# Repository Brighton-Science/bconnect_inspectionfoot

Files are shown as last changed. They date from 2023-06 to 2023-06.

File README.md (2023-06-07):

# The BC Mobile & Surface Analyst Custom Inspection Attachment

## INTRODUCTION:
This readme is intended to help the end user successfully design and fabricate their own custom foot known as a CIA(Custom Inspection Attachment).

## DESCRIPTION:
The standard attachment works very well mating to a flat surface. It does not facilitate the ability to measure on surfaces that have more complex features or geometry. 

3D printing technology allows a mechanical designer to create a CIA in house to quickly adapt the Surface Analyst to their particular substrate(s).  Although many additive manufactoring techiques are available the primary design intent for the information provided is for FDM printing using black material.

## USAGE:
Using both .pdf files of the “Tethered Universal head template” and “Tethered Universal CIA template” blueprints, design and fabrication of a CIA is made easier. Critical dimensions and noted drop placement will assist in helping construct a CIA that successfully allows the technician the ability to land a drop properly and gather contact angle readings. Both .pdf files will also provide the dimensional information required to use the 1/4-20 mounting features on the side of the measurement head.

Using the .stp files of both the “Tethered Universal head template” and “Tethered Universal CIA template” will allow the CAD designer to interface with the architecture directly.  Material can be added or removed to allow the designer to make proper engagement with the mating geometry.

## ASSISTANCE:
For more information or to request a quote for Brighton Science CIA services visit the site below:

https://www.brighton-science.com/solutions/non-networked-solutions/accessories-fixtures

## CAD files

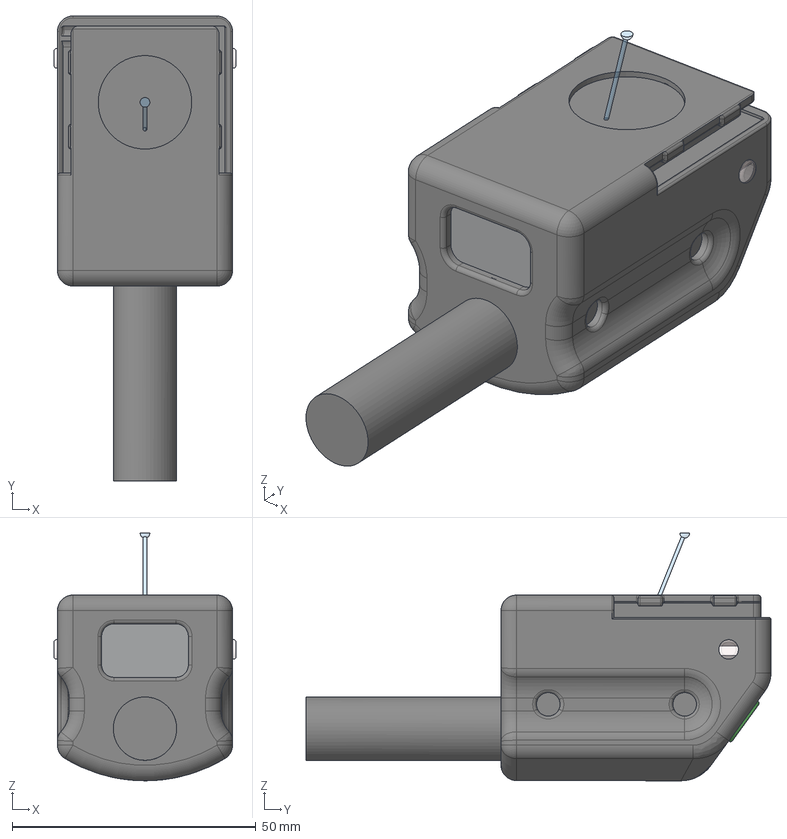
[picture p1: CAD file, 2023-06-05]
Tethered Universal Head template.stp
37.3 x 95.4 x 50.8 mm

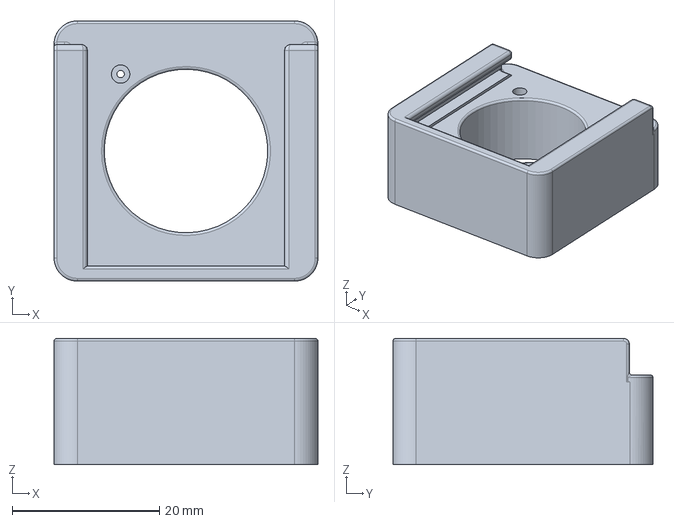
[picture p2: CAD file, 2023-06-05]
Tethered Universal CIA template.stp
35.9 x 35.4 x 17.2 mm

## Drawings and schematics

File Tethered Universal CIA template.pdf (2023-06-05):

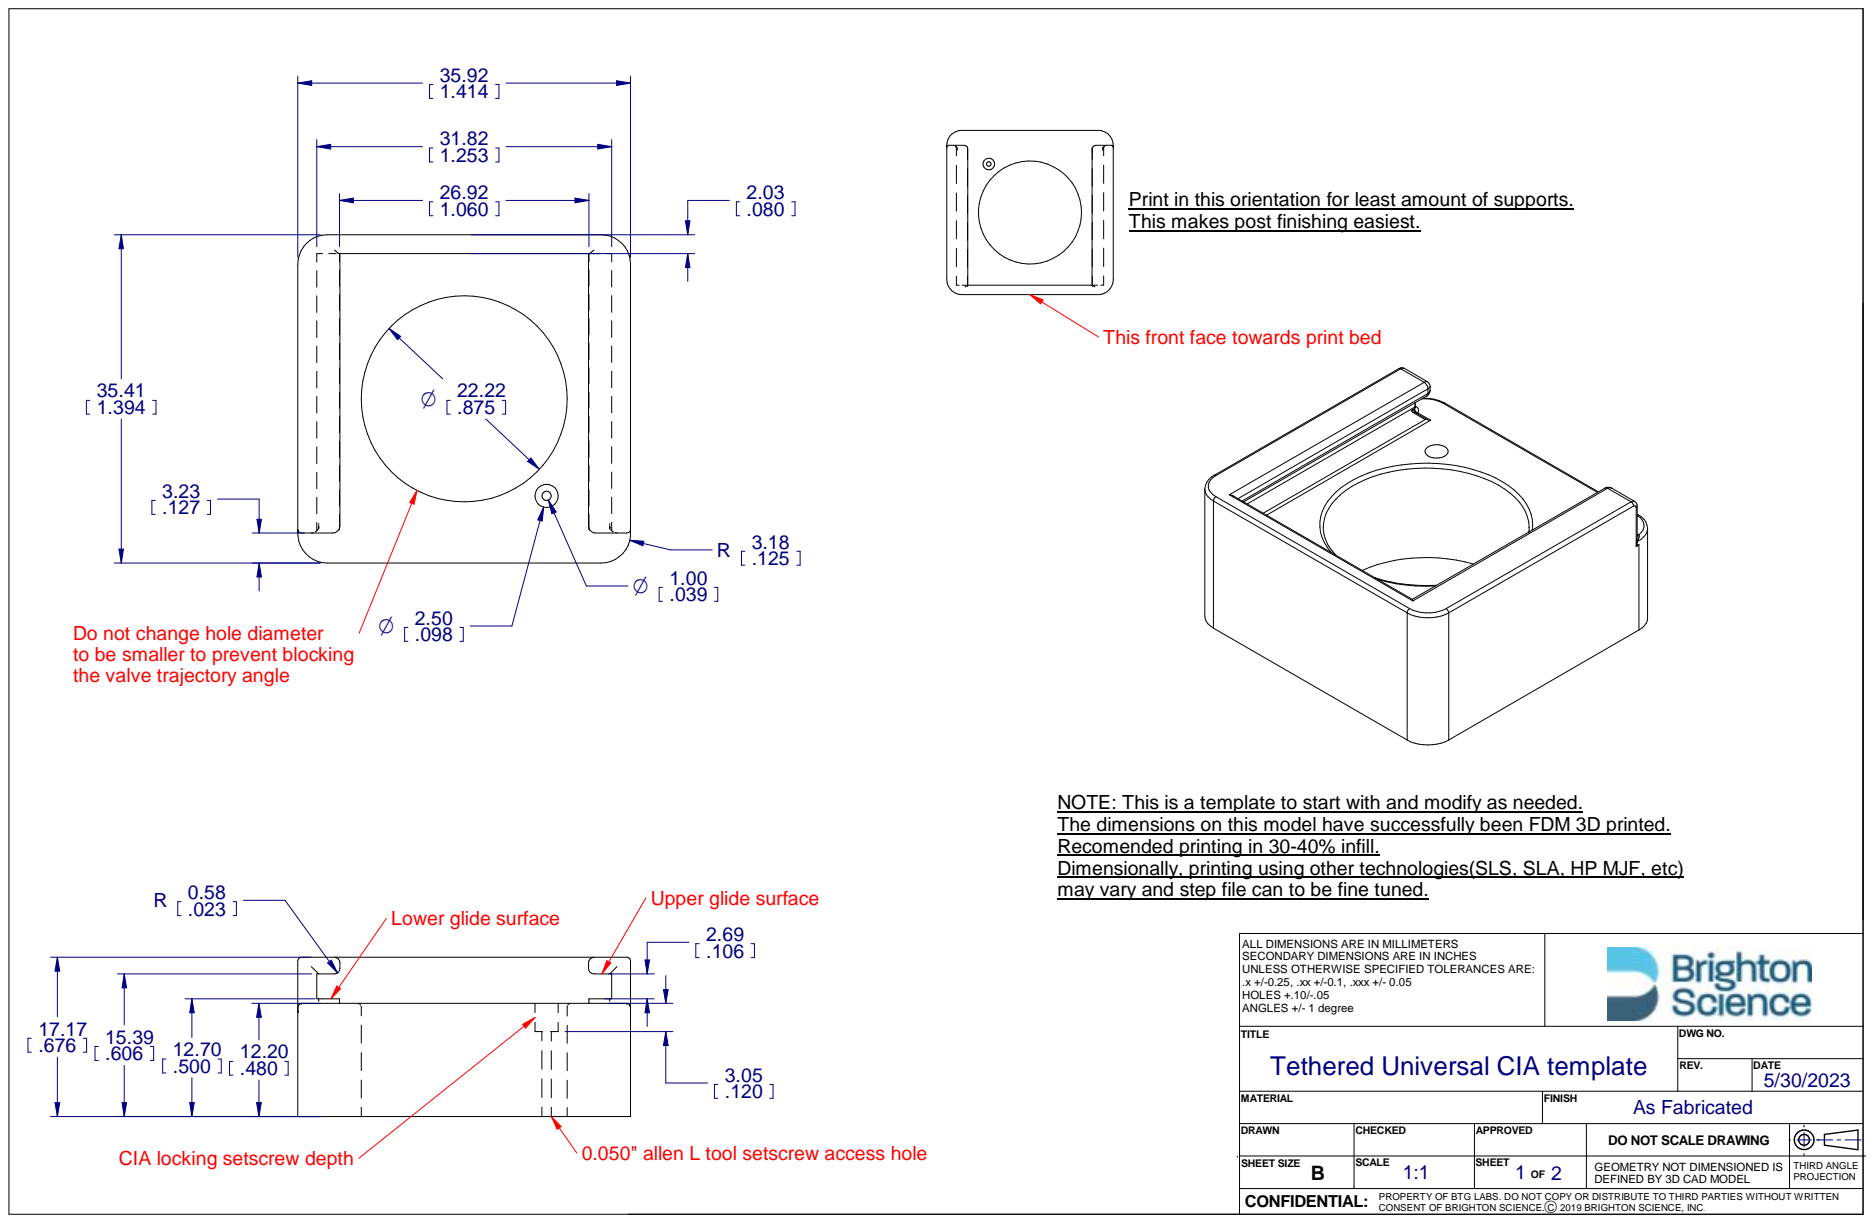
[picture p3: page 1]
CONFIDENTIAL:

Print in this orientation for least amount of supports.
This makes post finishing easiest.

This front face towards print bed

Do not change hole diameter
to be smaller to prevent blocking
the valve trajectory angle

NOTE: This is a template to start with and modify as needed.
The dimensions on this model have successfully been FDM 3D printed.
Recomended printing in 30-40% infill.
Dimensionally, printing using other technologies(SLS, SLA, HP MJF, etc)

may vary and step file can to be fine tuned. Upper glide surface

Lower glide surface

ALL DIMENSIONS ARE IN MILLIMETERS SECONDARY DIMENSIONS ARE IN INCHES UNLESS OTHERWISE SPECIFIED TOLERANCES ARE: .x +/-0.25, .xx +/-0.1, .xxx +/- 0.05 HOLES +.10/-.05 ANGLES +/- 1 degree

TITLE Tethered Universal CIA template | DWG NO.

REV. | DATE 5/30/2023

MATERIAL | FINISH As Fabricated

DRAWN | CHECKED | APPROVED | DO NOT SCALE DRAWING

0.050" allen L tool setscrew access hole

CIA locking setscrew depth

SHEET SIZE B | SCALE | SHEET 1 | GEOMETRY NOT DIMENSIONED IS DEFINED BY 3D CAD MODEL | THIRD ANGLE PROJECTION

PROPERTY OF BTG LABS. DO NOT COPY OR DISTRIBUTE TO THIRD PARTIES WITHOUT WRITTEN
CONSENT OF BRIGHTON SCIENCE. C 2019 BRIGHTON SCIENCE, INC.

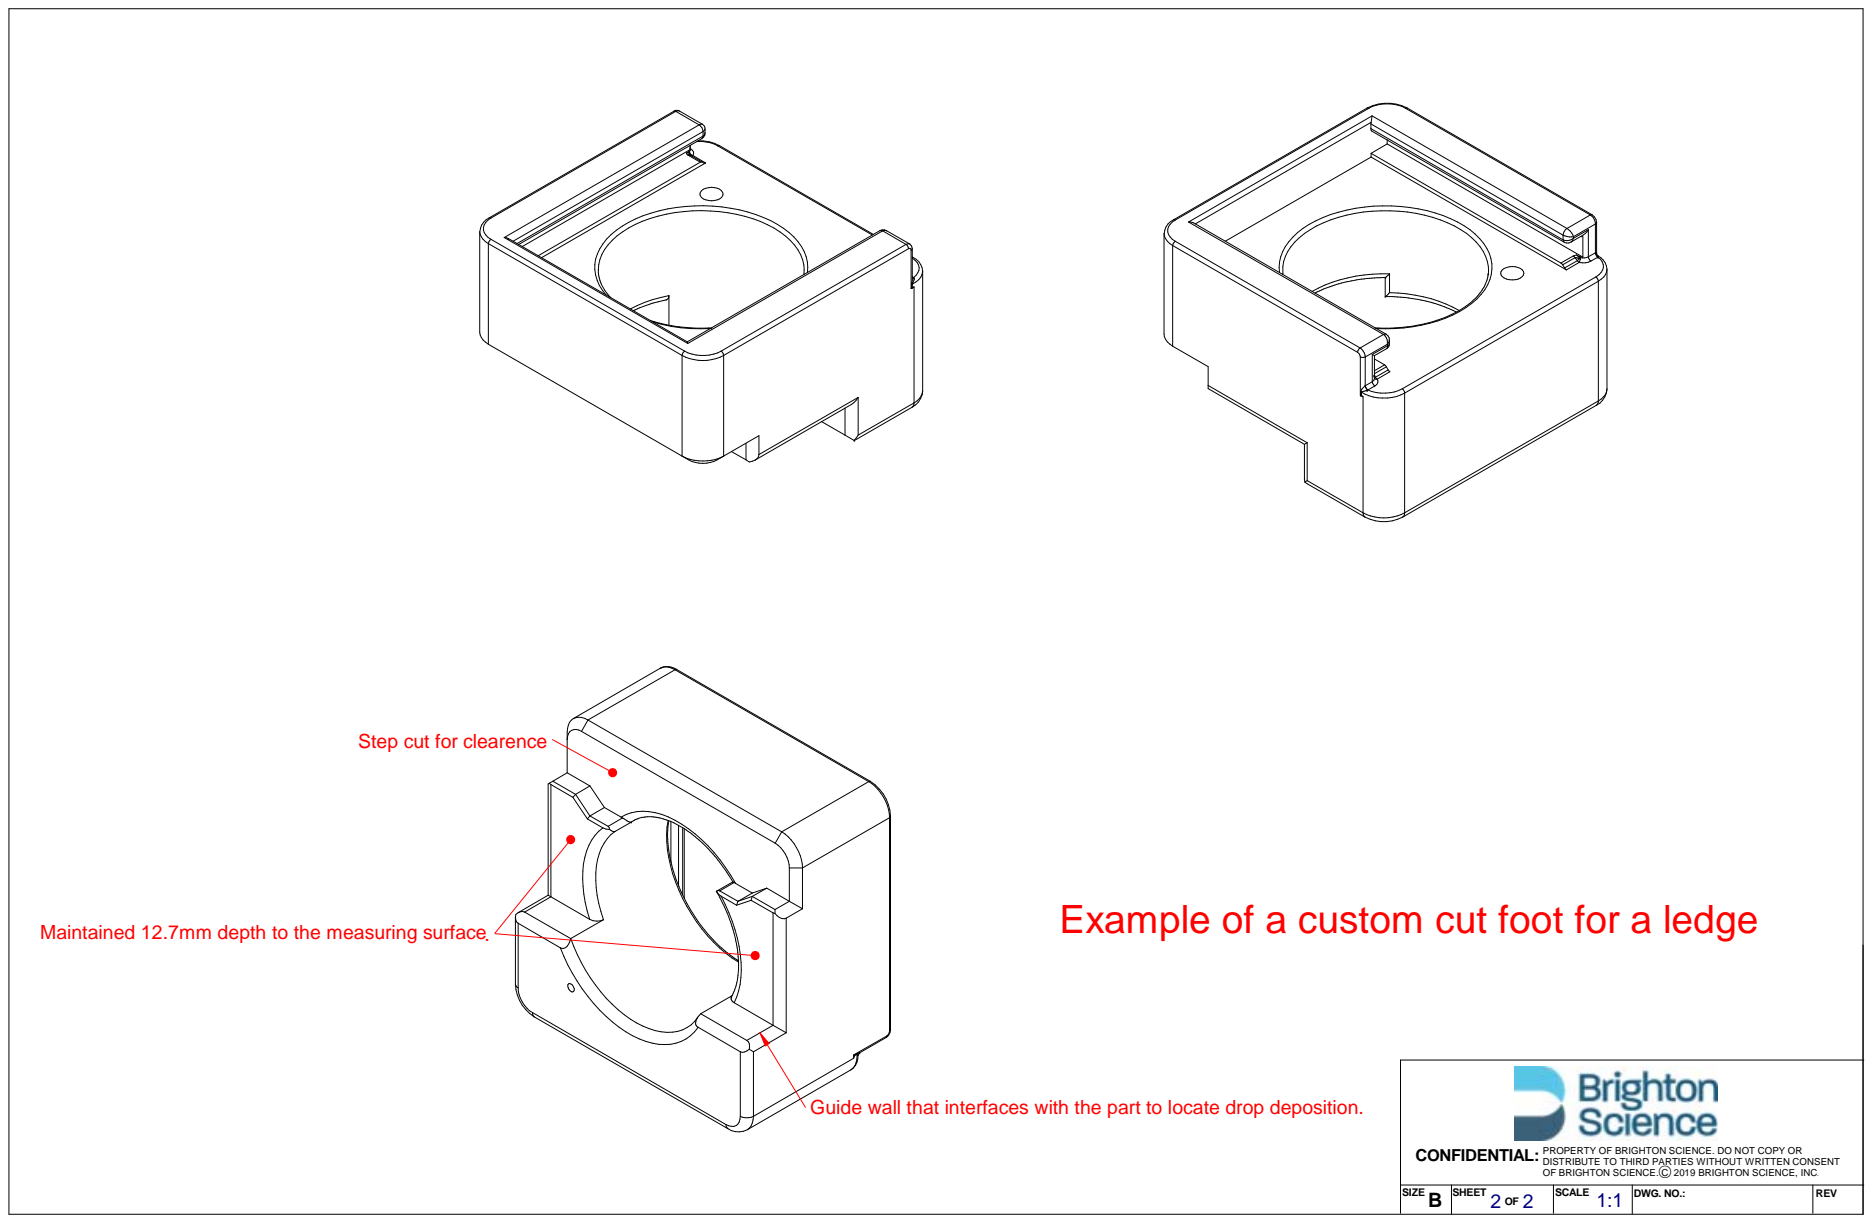
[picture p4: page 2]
REV; 2 SIZE; SHEET; SCALE; DWG. NO.:; CONFIDENTIAL:

Step cut for clearence

Example of a custom cut foot for a ledge

Maintained 12.7mm depth to the measuring surface

Guide wall that interfaces with the part to locate drop deposition.

PROPERTY OF BRIGHTON SCIENCE. DO NOT COPY OR
DISTRIBUTE TO THIRD PARTIES WITHOUT WRITTEN CONSENT
OF BRIGHTON SCIENCE. C 2019 BRIGHTON SCIENCE, INC.

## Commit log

2023-06-05 First commit
    First commit
    [Tethered Universal CIA template.stp, Tethered Universal Head template.stp]
2024-02-08 Add files via upload
    Added additional measurement for camera location
